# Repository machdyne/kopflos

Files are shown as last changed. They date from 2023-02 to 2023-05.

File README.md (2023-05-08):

# Kopflos Computer

Kopflos is a headless FPGA computer designed by Lone Dynamics Corporation.

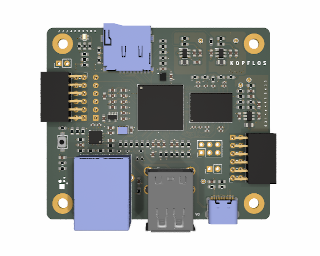
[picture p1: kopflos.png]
Kopflos Computer


This repo contains schematics, PCB layouts, pinouts, a 3D-printable case, example gateware and documentation.

Find more information on the [Kopflos product page](https://machdyne.com/product/kopflos-computer/).

## Programming Kopflos

Kopflos has a JTAG interface and ships with a [DFU bootloader](https://github.com/machdyne/tinydfu-bootloader) that allows the included flash [MMOD](https://machdyne.com/product/mmod) to be programmed over the USB-C port.

### DFU

The DFU bootloader is available for 5 seconds after power-on, issuing a DFU command during this period will stop the boot process until the DFU device is detached. If no command is received the boot process will continue and the user gateware will be loaded.

Install [dfu-util](http://dfu-util.sourceforge.net) (Debian/Ubuntu):

```
$ sudo apt install dfu-util
```

Update the user gateware on the flash MMOD:

```
$ sudo dfu-util -a 0 -D image.bit
```

Detach the DFU device and continue the boot process:

```
$ sudo dfu-util -a 0 -e
```

It is possible to update the bootloader itself using DFU but you shouldn't attempt this unless you have a JTAG programmer (or another method to program the MMOD) available, in case you need to restore the bootloader.

### JTAG

These examples assume you're using a "USB Blaster" JTAG cable, see the header pinout below. You will need to have [openFPGALoader](https://github.com/trabucayre/openFPGALoader) installed.

Program the configuration SRAM:

```
openFPGALoader -c usb-blaster image.bit
```

Program the flash MMOD:

```
openFPGALoader -f -c usb-blaster images/bootloader/tinydfu_kopflos.bit
```

## Blinky 

Building the blinky example requires [Yosys](https://github.com/YosysHQ/yosys), [nextpnr-ecp5](https://github.com/YosysHQ/nextpnr) and [Project Trellis](https://github.com/YosysHQ/prjtrellis).

Assuming they are installed, you can simply type `make` to build the gateware, which will be written to output/blinky.bin. You can then use [openFPGALoader](https://github.com/trabucayre/openFPGALoader) or dfu-util to write the gateware to the device.

## Linux

See the [Kakao Linux](https://github.com/machdyne/kakao) repo for detailed installation instructions.

## JTAG Header

The 3.3V JTAG header can be used to program the FPGA SRAM as well as the MMOD flash memory.

```
2 4 6
1 3 5
```

| Pin | Signal |
| --- | --- |
| 1 | TCK |
| 2 | TDI |
| 3 | TDO |
| 4 | TMS |
| 5 | 3V3 (out) |
| 6 | GND |

## Board Revisions

| Revision | Notes |
| --- | ----- |
| V0 | Initial version |

## License

The contents of this repo are released under the [Lone Dynamics Open License](LICENSE.md) with the following exceptions:

- The KiCad design files contain parts of the [kicad-pmod](https://github.com/mithro/kicad-pmod) library which is released under the [Apache License, Version 2.0](https://www.apache.org/licenses/LICENSE-2.0.html).

- The KiCad design files may contain symbols and footprints released under other licenses; please contact us if we've failed to give proper attribution.

Note: You can use these designs for commercial purposes but we ask that instead of producing exact clones, that you either replace our trademarks and logos with your own or add your own next to ours.

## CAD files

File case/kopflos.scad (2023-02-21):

/*
 * Kopflos Case
 * Copyright (c) 2022 Lone Dynamics Corporation. All rights reserved.
 *
 * required hardware:
 *  - 4 x M3 x 25mm countersunk bolts
 *  - 4 x M3 nuts
 *
 */

$fn = 100;

board_width = 60;
board_thickness = 1.5;
board_length = 70;
board_height = 1.6;
board_spacing = 2;

wall = 1.5;

top_height = 17;
bottom_height = 8;

//mds_board();

translate([0,0,15])
	mds_case_top();

//translate([0,0,-15])
//	mds_case_bottom();

module mds_board() {
	
	translate([wall, wall, 0]) {
		difference() {
			color([0,0.5,0])
				roundedcube(board_width,board_length,board_thickness,3);
			translate([5, 5, -1]) cylinder(d=3.2, h=10);
			translate([5, 65, -1]) cylinder(d=3.2, h=10);
			translate([55, 5, -1]) cylinder(d=3.2, h=10);
			translate([55, 65, -1]) cylinder(d=3.2, h=10);
		}	
	}
	
}

module mds_case_top() {
	
	difference() {
				
		color([0.5,0.5,0.5])
			roundedcube(board_width+(wall*2),board_length+(wall*2),top_height,2.5);

		// cutouts
		translate([2,9,-12])
			roundedcube(board_width-3,board_length-15,13.75,2.5);

		translate([2,9,-2])
			roundedcube(board_width-6,board_length-15,13.75,2.5);

		translate([9,3,-2])
			roundedcube(board_width-15,board_length-3,17.75,2.5);
		
		translate([wall, wall, 0]) {

			// vents
			translate([60/2-(30/2),60,0]) cube([30,1,20]);
			translate([60/2-(30/2),55,0]) cube([30,1,20]);
			translate([60/2-(30/2),50,0]) cube([30,1,20]);
					
			// Ethernet
			translate([40,18.5-(16/2),-1]) cube([30,16,14+1]);

			// USBA
			translate([40,38.5-(16/2),-1]) cube([30,16,15.7+1]);

			// USBC
			translate([40,55-(9.5/2),-1]) cube([30,9.5,3.5+1]);
		
			// SD
			translate([-5,25.3-(15/2),-1]) cube([30,15,2+1]);

			// PMODA
			translate([21.775-(15.6/2),-5,-1]) cube([15.6,30,5+1]);

			// PMODB
			translate([40.675-(15.6/2),65,-1]) cube([15.6,30,5+1]);

			// LED
			translate([-5,11.5-(1.5/2),3.5]) cube([25,1.5,1.5]);
				
			// bolt holes
			translate([5, 5, -21]) cylinder(d=3.5, h=40);
			translate([5, 65, -21]) cylinder(d=3.5, h=40);
			translate([55, 5, -20]) cylinder(d=3.5, h=40);
			translate([55, 65, -21]) cylinder(d=3.5, h=40);

			// flush mount bolt holes
			translate([5, 5, top_height-2]) cylinder(d=5, h=4);
			translate([5, 65, top_height-2]) cylinder(d=5, h=4);
			translate([55, 5, top_height-2]) cylinder(d=5, h=4);
			translate([55, 65, top_height-2]) cylinder(d=5, h=4);

			// eis text
			rotate(270)
				translate([-23.5,30-3,top_height-0.5])
					linear_extrude(1)
						text("K O P F L O S", size=5, halign="center",
							font="Ubuntu:style=Bold");

		}
		
	}	
}

module mds_case_bottom() {
	
	difference() {
		color([0.5,0.5,0.5])
			roundedcube(board_width+(wall*2),board_length+(wall*2),bottom_height,2.5);
		
		// cutouts
		translate([3,10,1.5])
			roundedcube(board_width-3,board_length-17,10,2.5);
				
		translate([10.5,2.5,1.5])
			roundedcube(board_width-17.5,board_length-2,10,2.5);

		translate([wall, wall, 0]) {
			
		// board cutout
		translate([0,0,bottom_height-board_height])
			roundedcube(board_width+0.2,board_length+0.2,board_height+1,2.5);

		translate([wall, wall, 0]) {

			// USB-C
			translate([39,55-(9.5/2),5]) cube([19.75,9.5,10.5+1]);
			
		}

		// bolt holes
		translate([5, 5, -11]) cylinder(d=3.2, h=25);
		translate([5, 65, -11]) cylinder(d=3.2, h=25);
		translate([55, 5, -11]) cylinder(d=3.2, h=25);
		translate([55, 65, -11]) cylinder(d=3.2, h=25);

		// nut holes
		translate([5, 5, -1]) cylinder(d=7, h=2.5+2, $fn=6);
		translate([5, 65, -1]) cylinder(d=7, h=2.5+2, $fn=6);
		translate([55, 5, -1]) cylinder(d=7, h=2.5+2, $fn=6);
		translate([55, 65, -1]) cylinder(d=7, h=2.5+2, $fn=6);

		}
		
	}	
}

// https://gist.github.com/tinkerology/ae257c5340a33ee2f149ff3ae97d9826
module roundedcube(xx, yy, height, radius)
{
    translate([0,0,height/2])
    hull()
    {
        translate([radius,radius,0])
        cylinder(height,radius,radius,true);

        translate([xx-radius,radius,0])
        cylinder(height,radius,radius,true);

        translate([xx-radius,yy-radius,0])
        cylinder(height,radius,radius,true);

        translate([radius,yy-radius,0])
        cylinder(height,radius,radius,true);
    }
}

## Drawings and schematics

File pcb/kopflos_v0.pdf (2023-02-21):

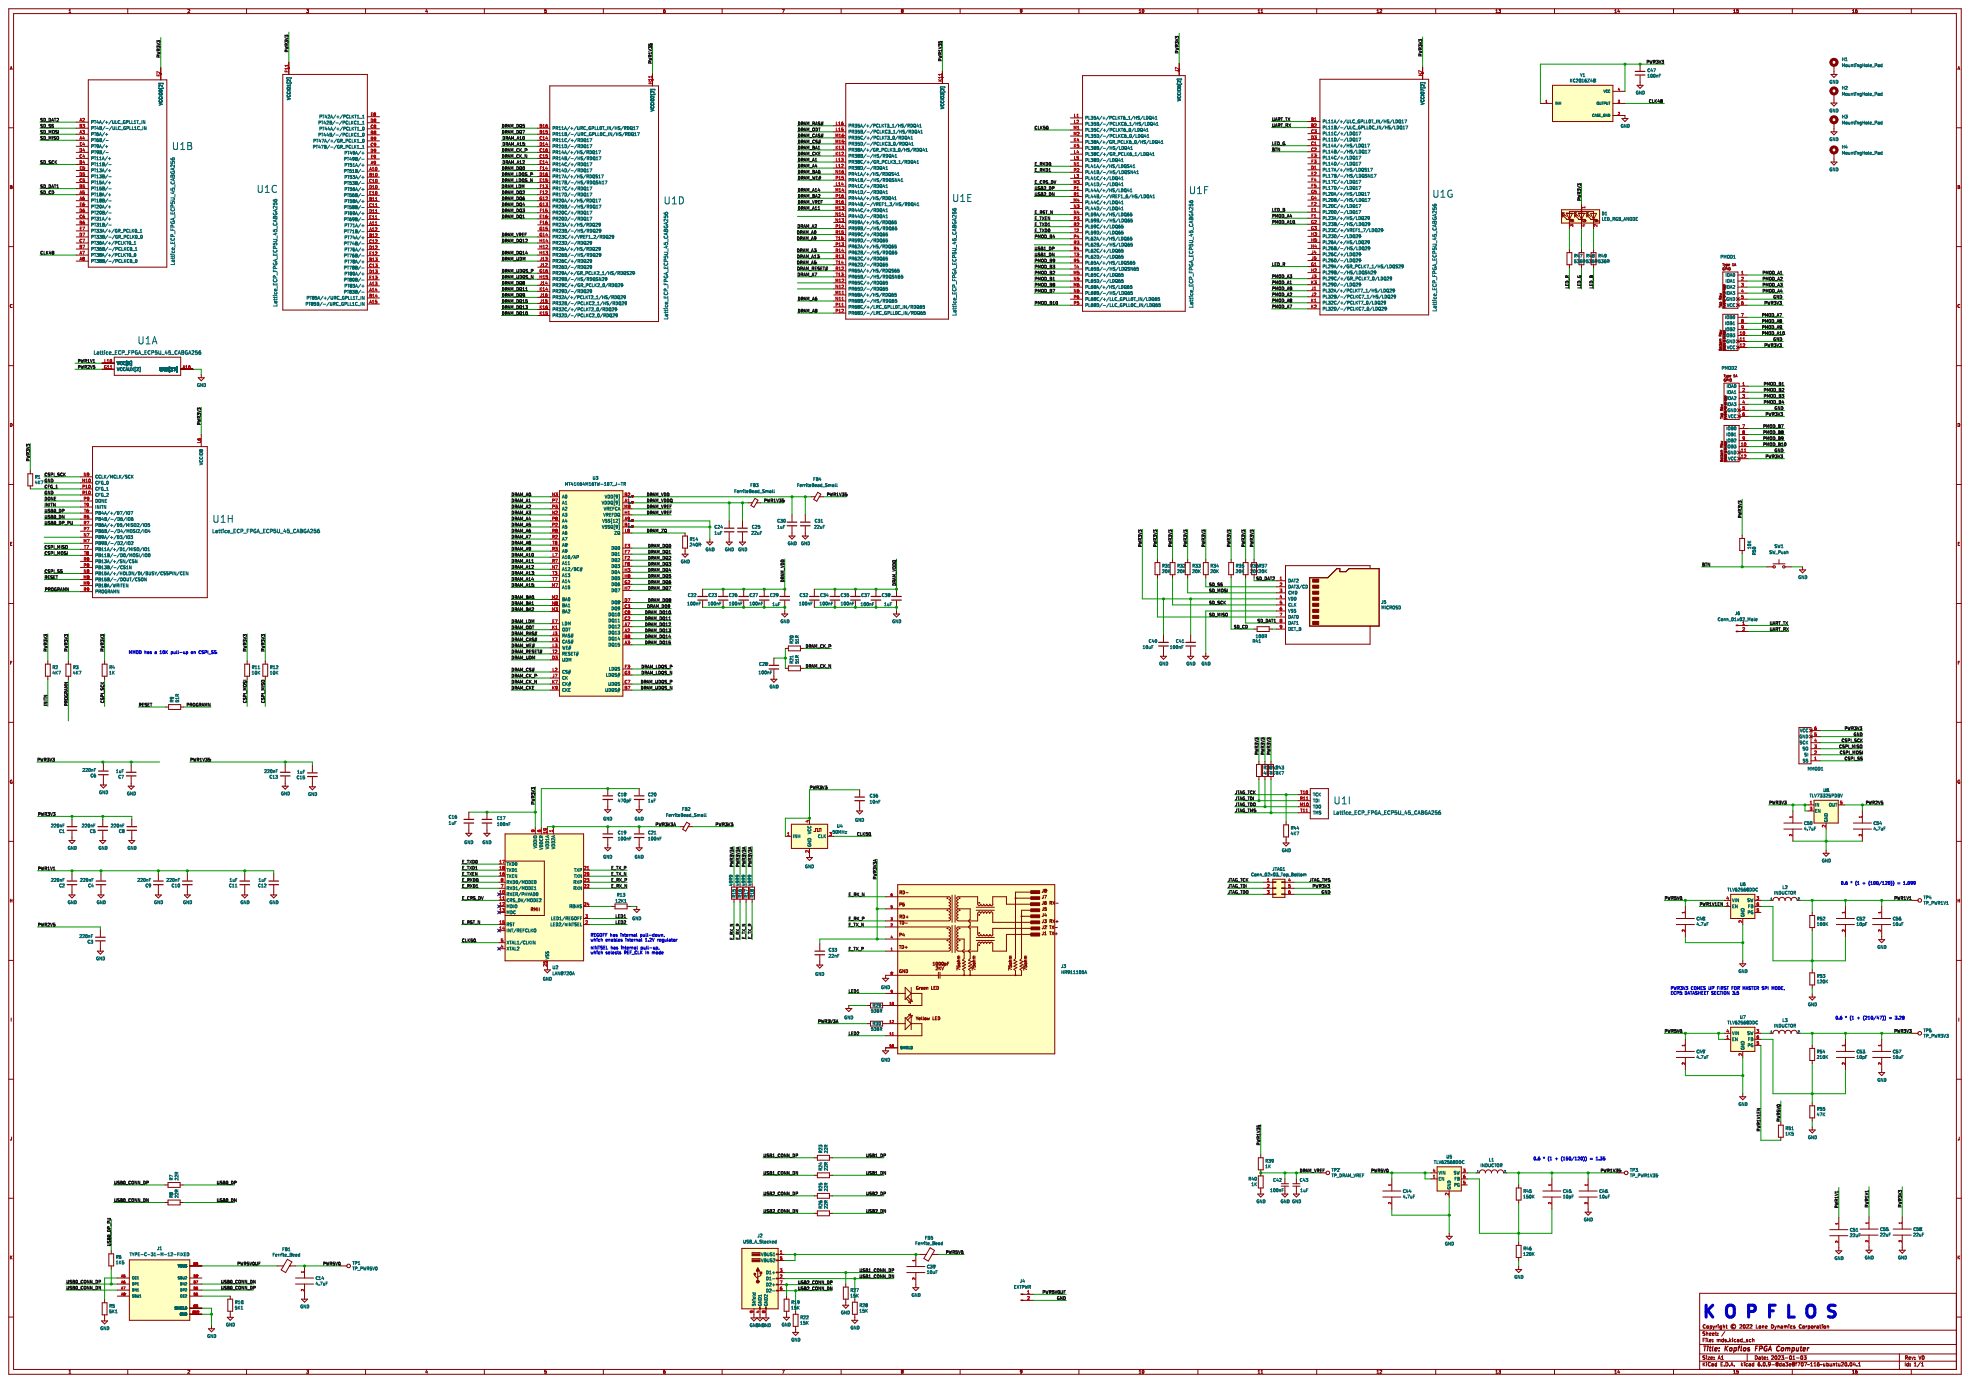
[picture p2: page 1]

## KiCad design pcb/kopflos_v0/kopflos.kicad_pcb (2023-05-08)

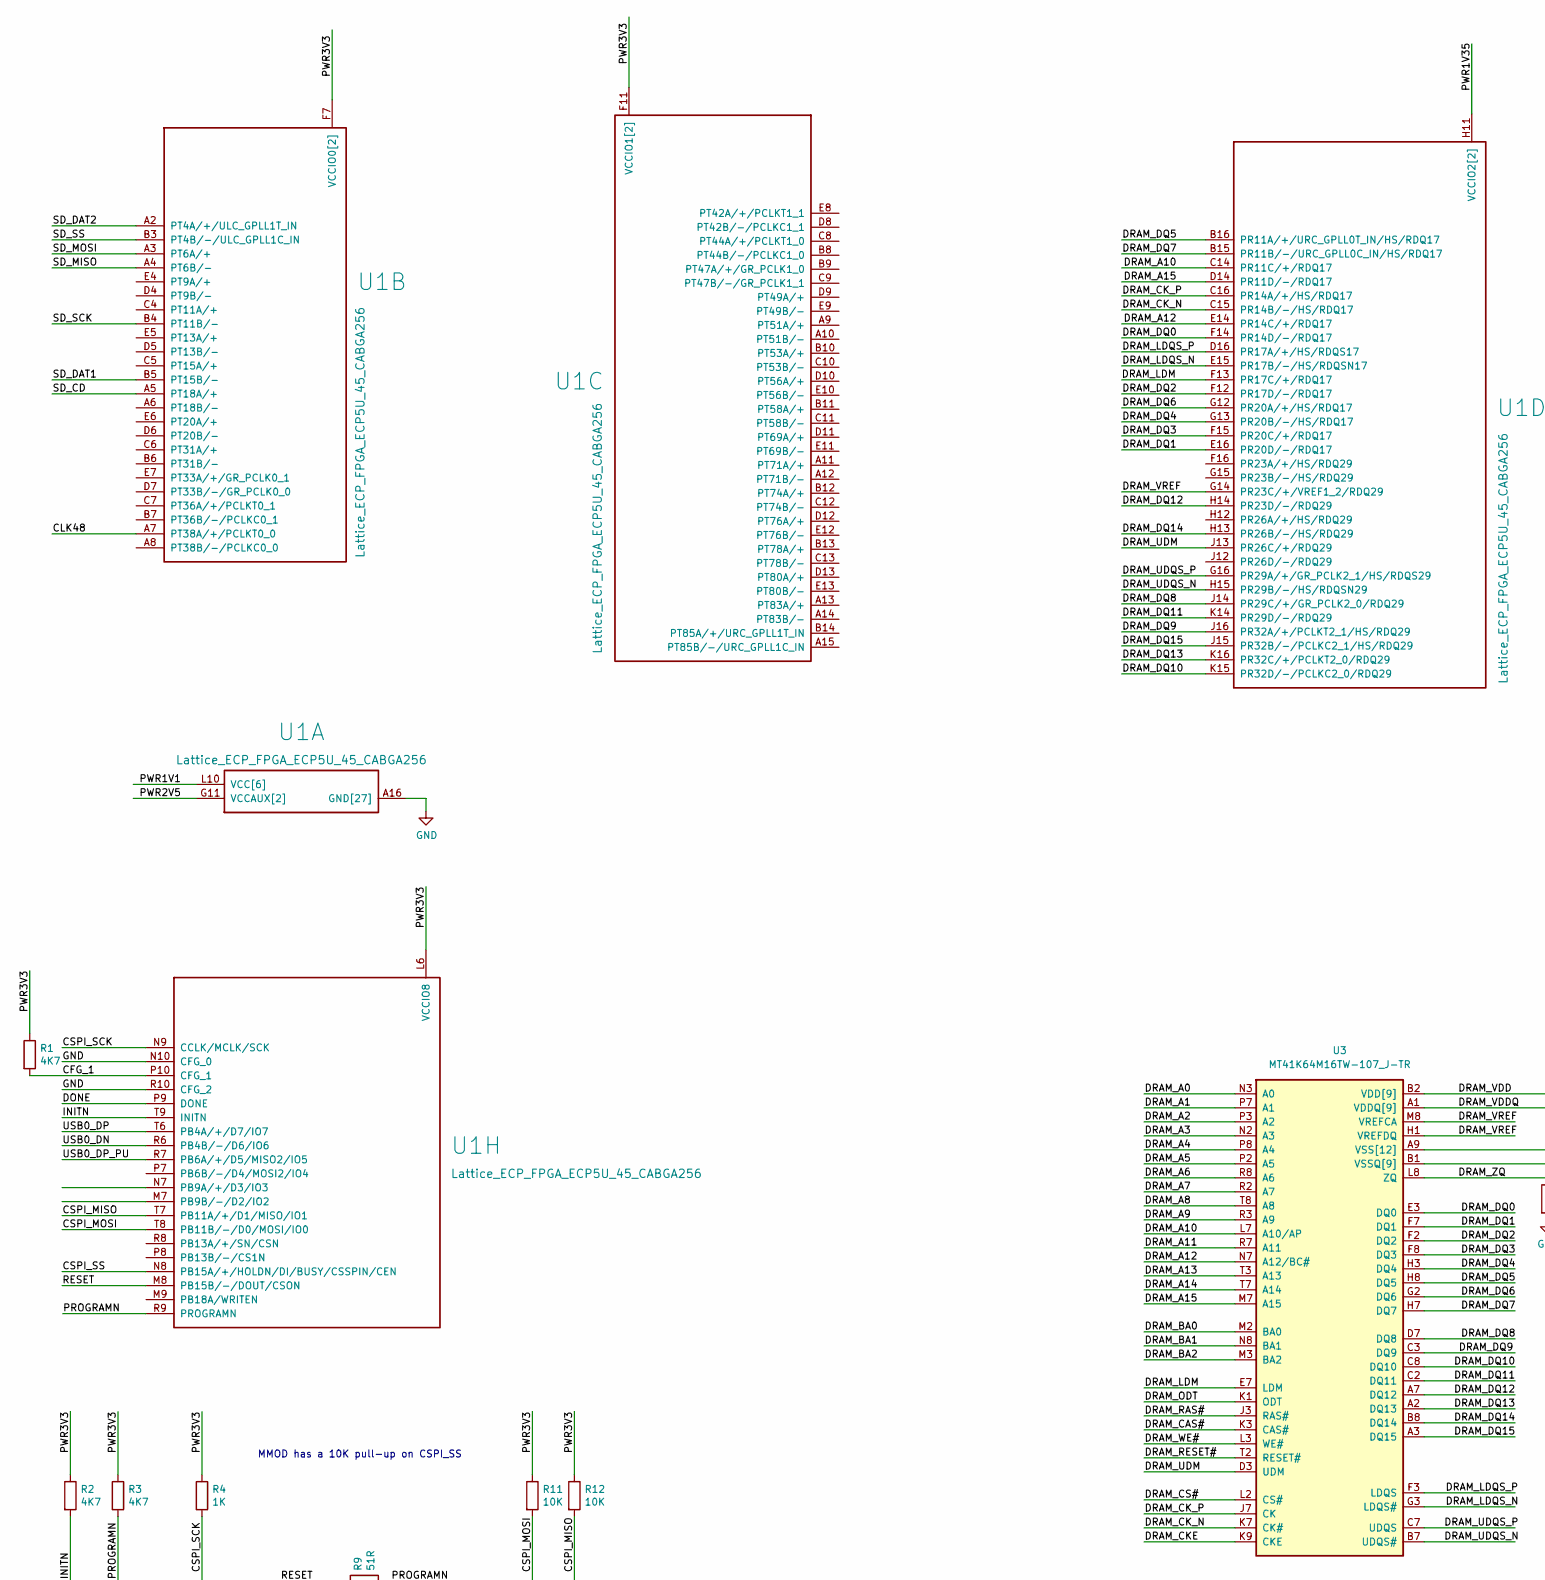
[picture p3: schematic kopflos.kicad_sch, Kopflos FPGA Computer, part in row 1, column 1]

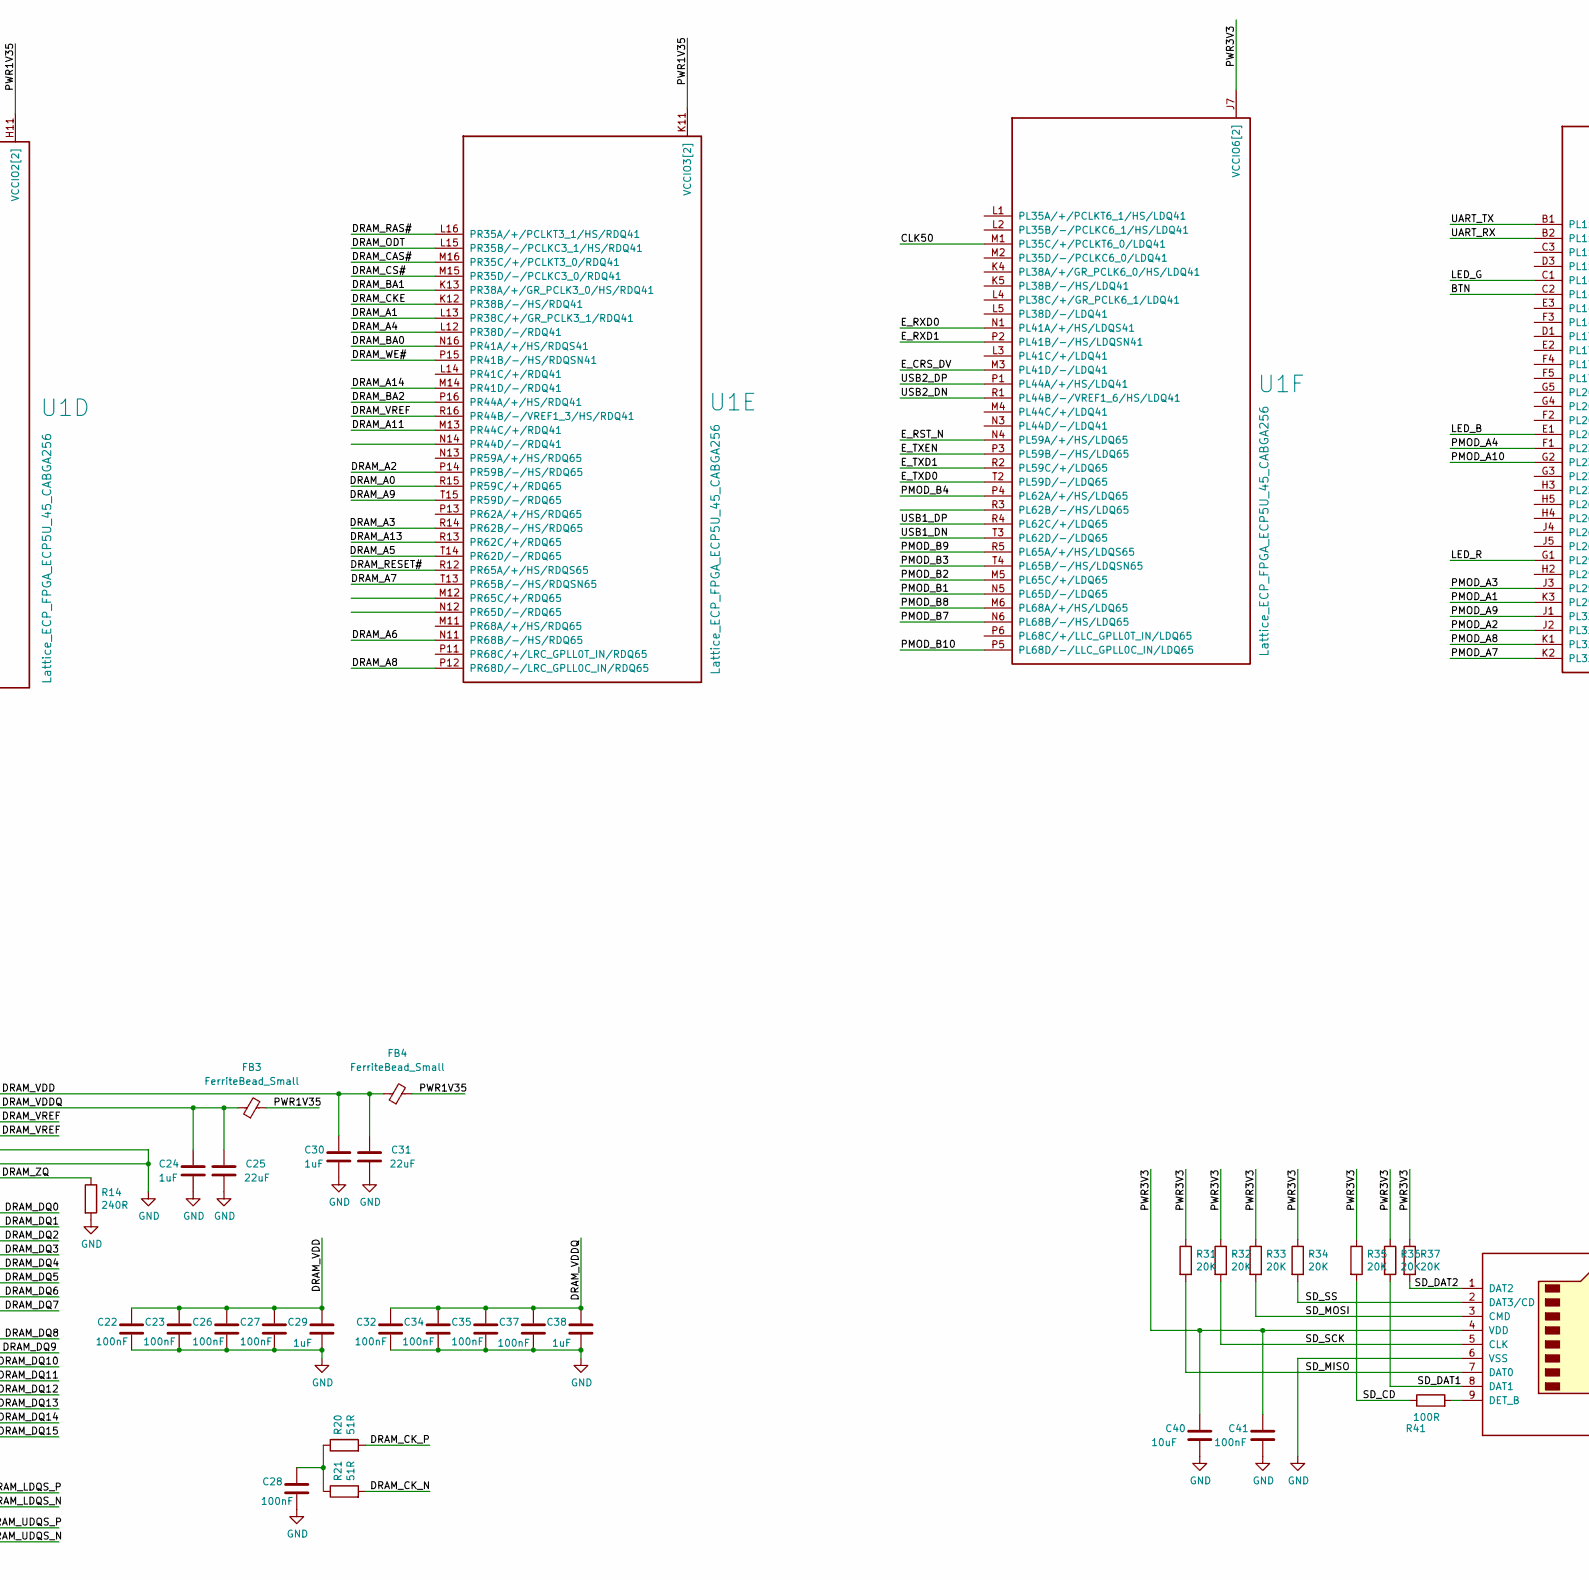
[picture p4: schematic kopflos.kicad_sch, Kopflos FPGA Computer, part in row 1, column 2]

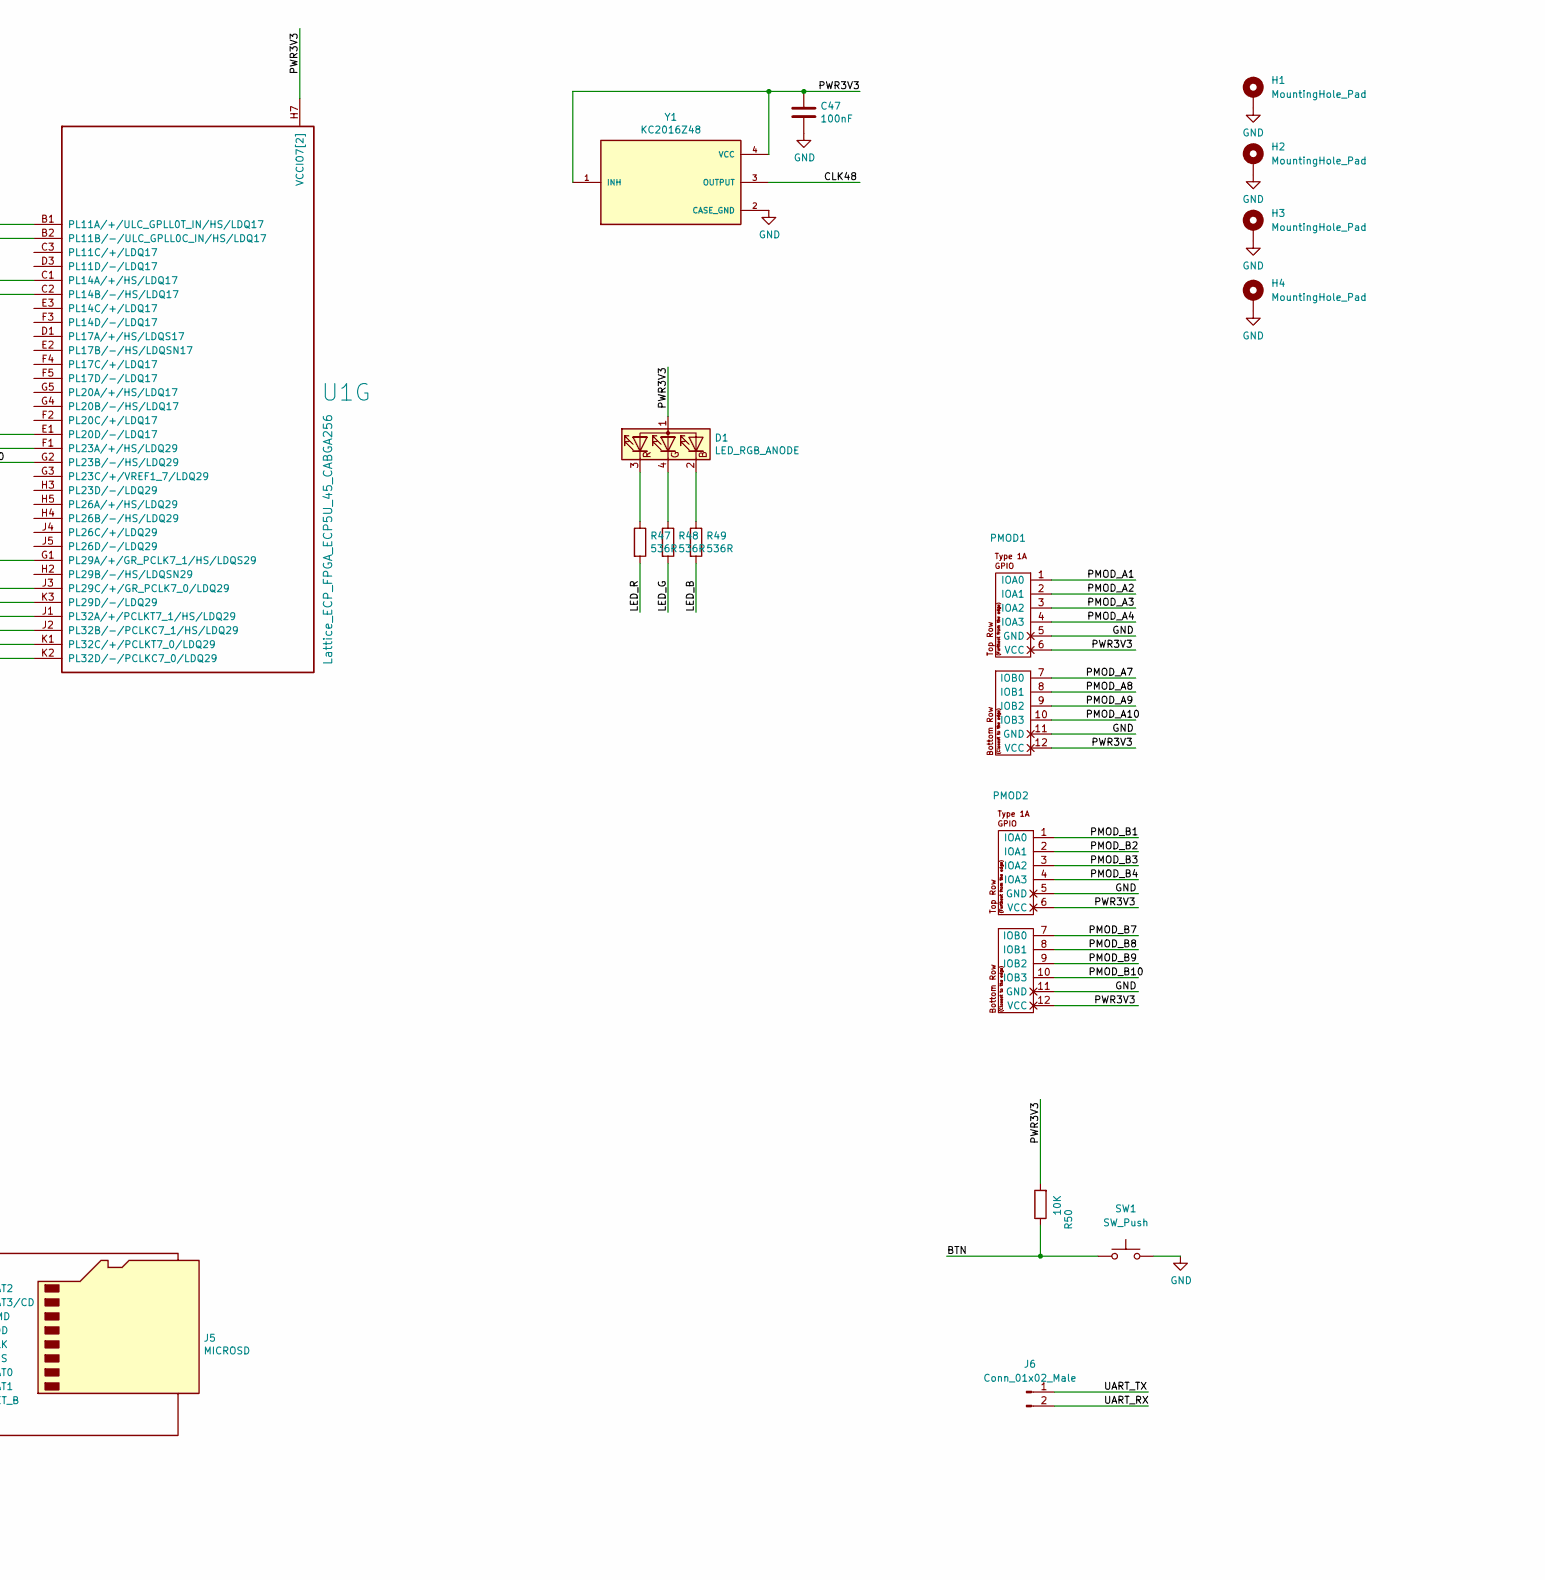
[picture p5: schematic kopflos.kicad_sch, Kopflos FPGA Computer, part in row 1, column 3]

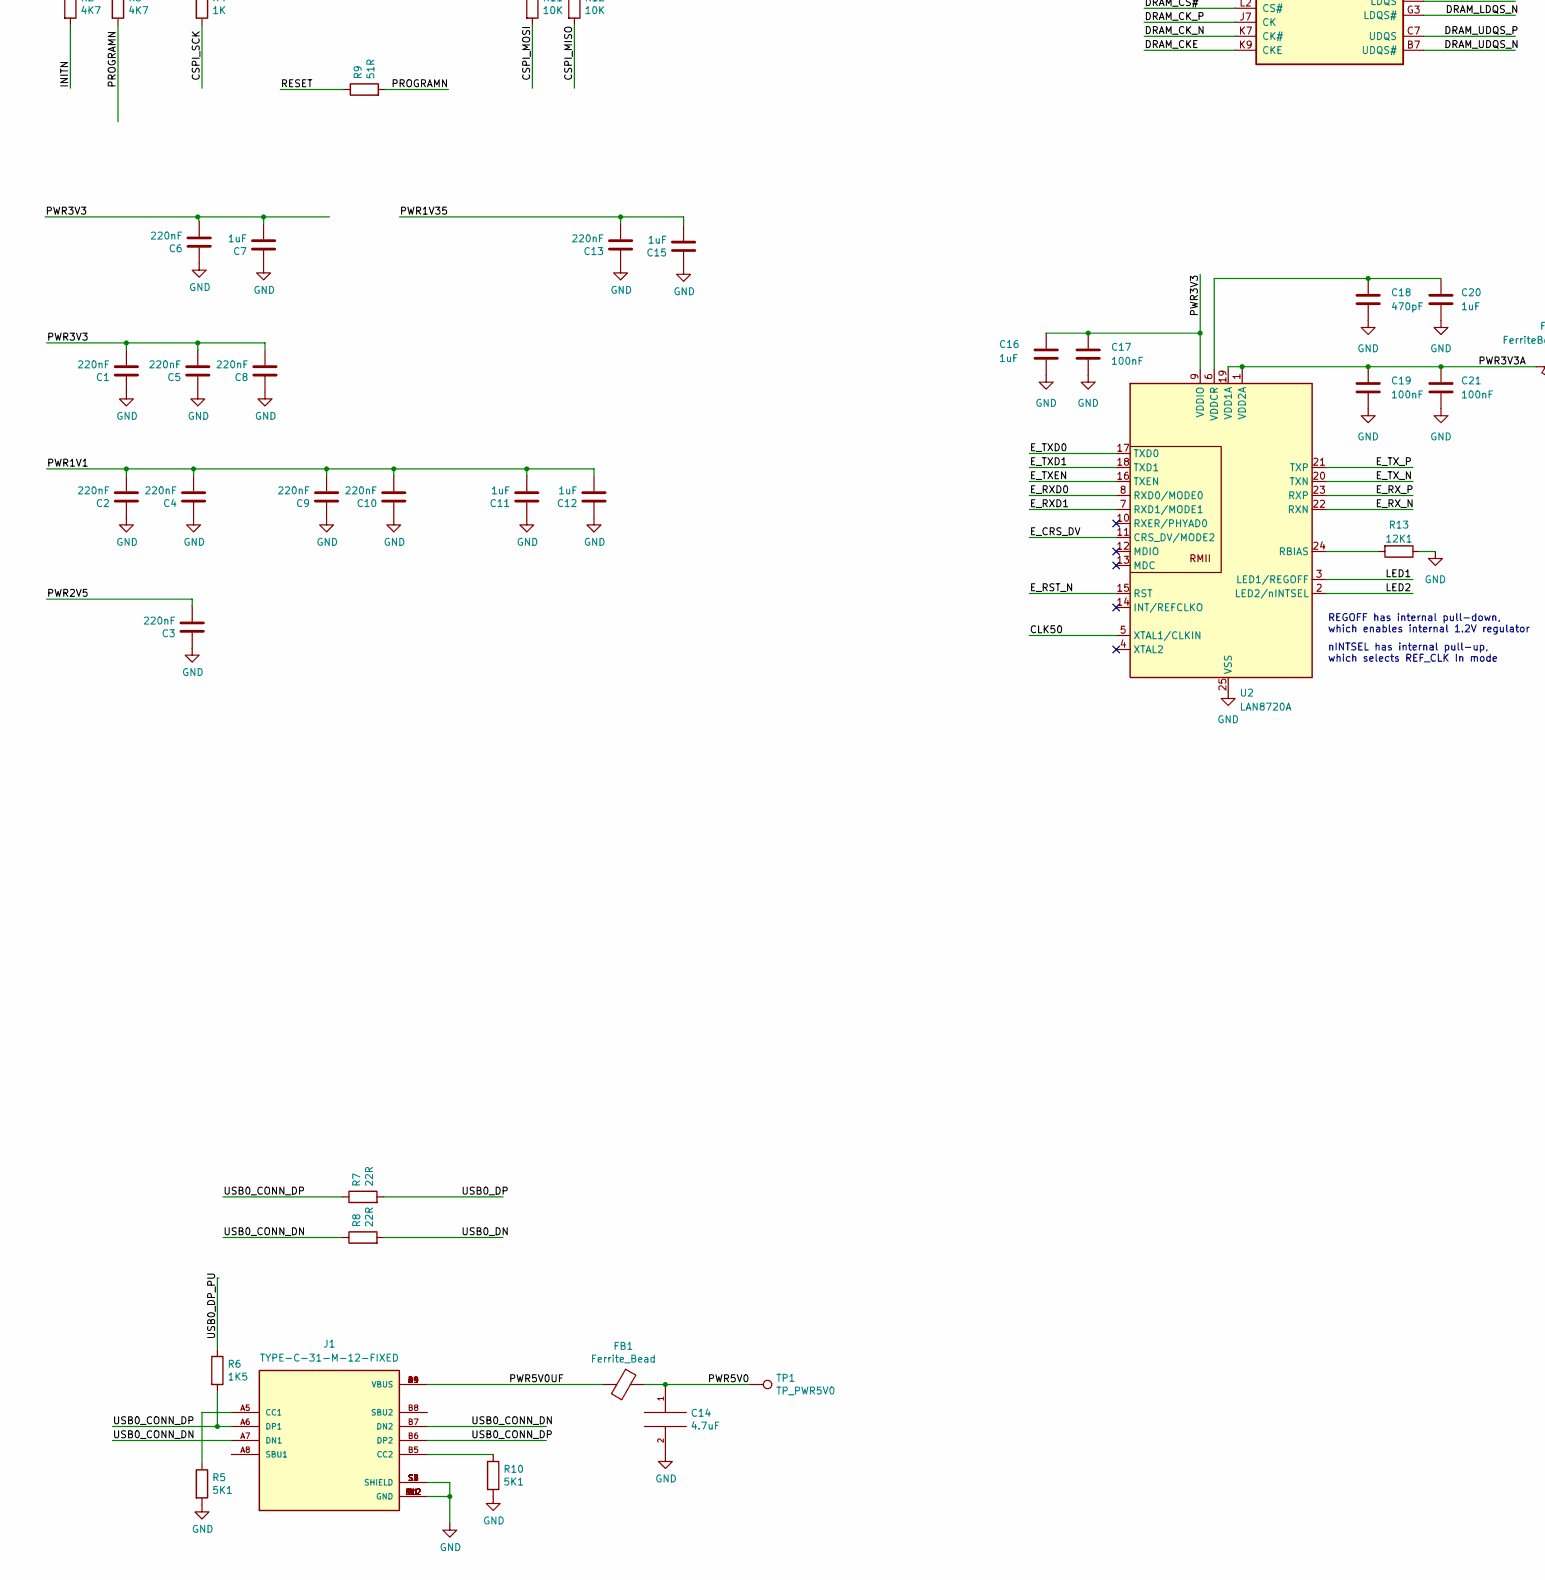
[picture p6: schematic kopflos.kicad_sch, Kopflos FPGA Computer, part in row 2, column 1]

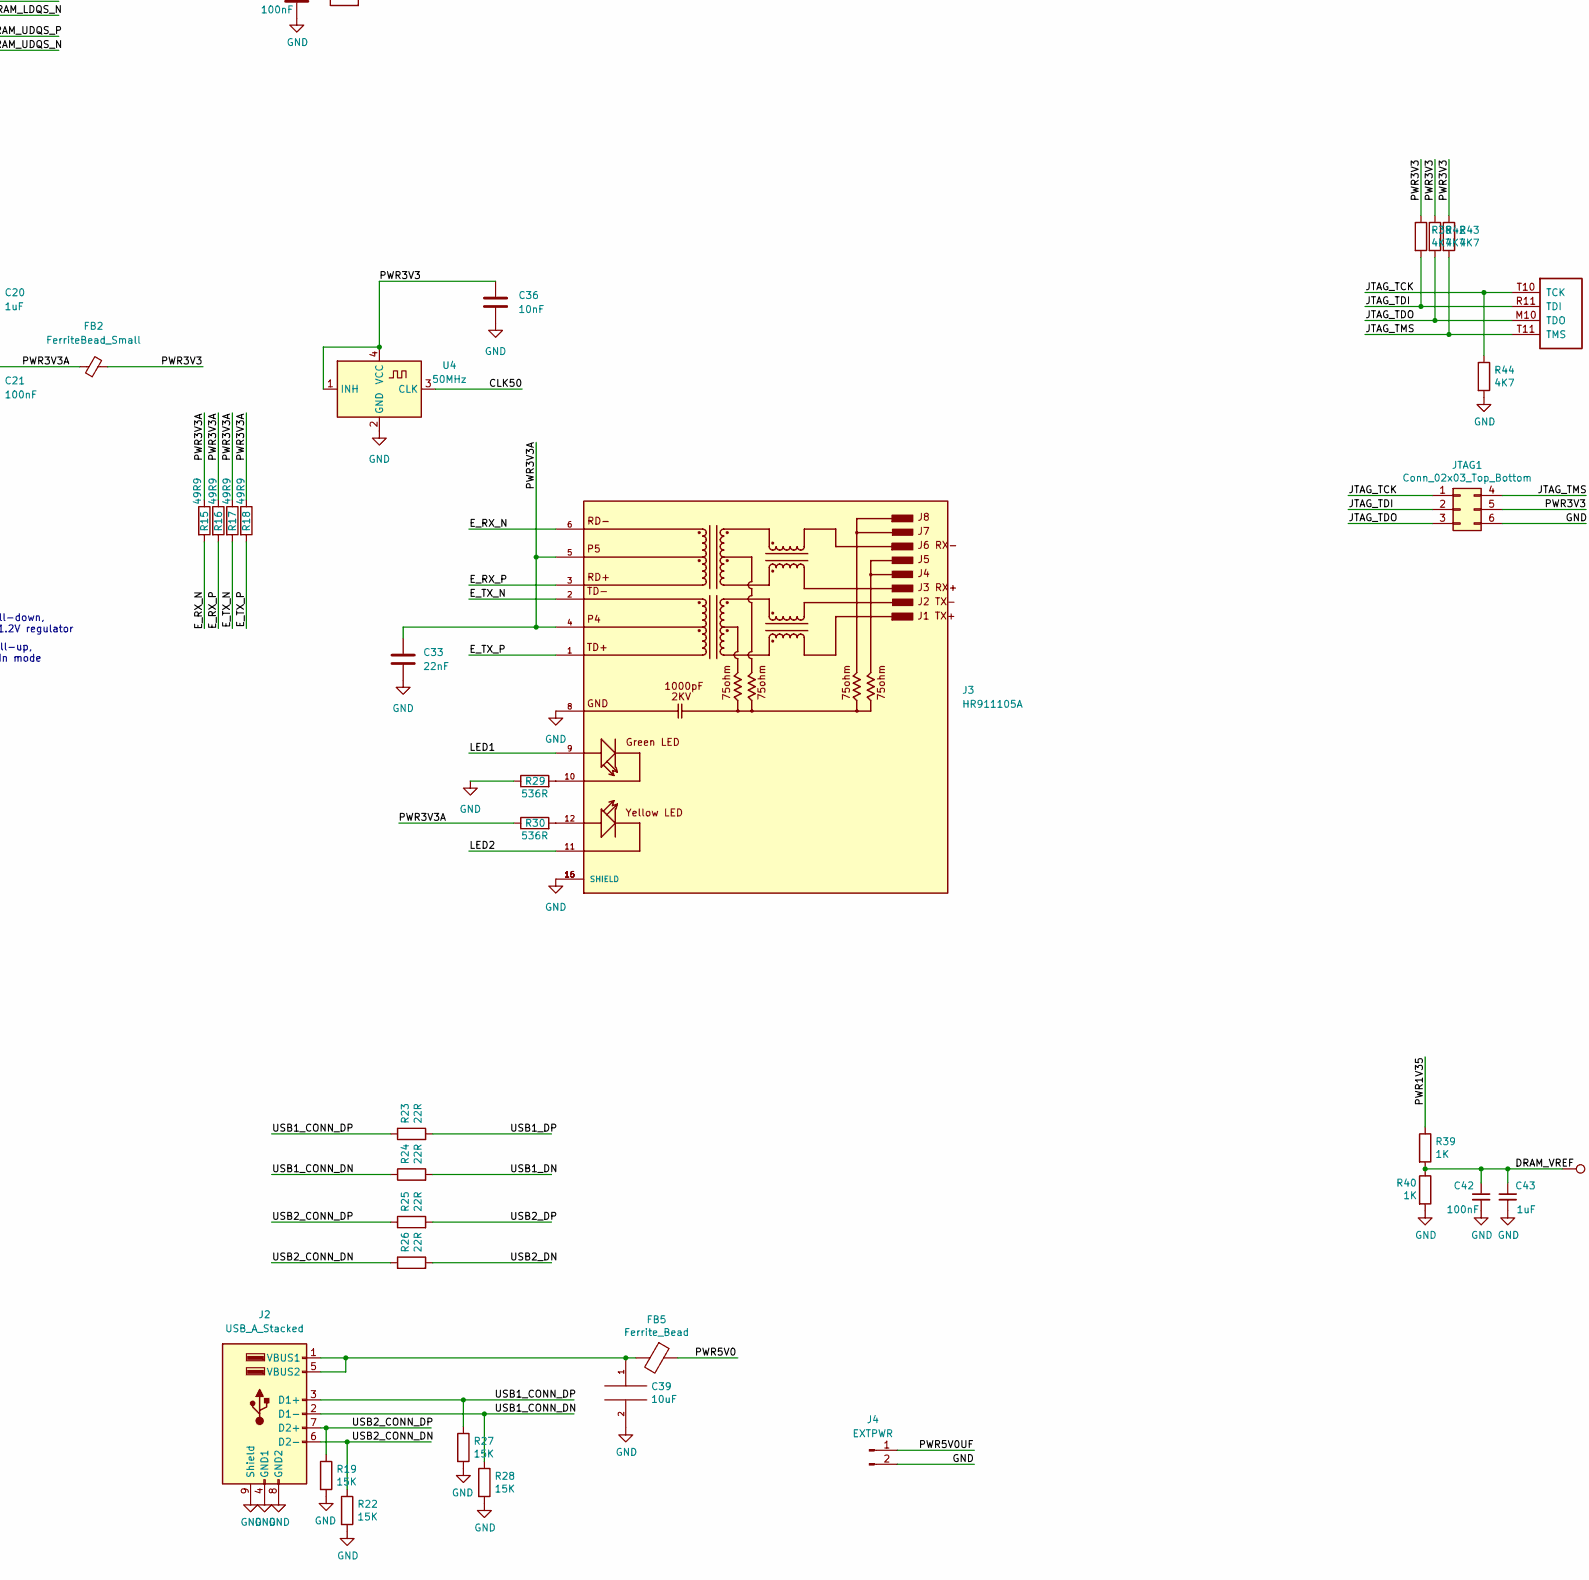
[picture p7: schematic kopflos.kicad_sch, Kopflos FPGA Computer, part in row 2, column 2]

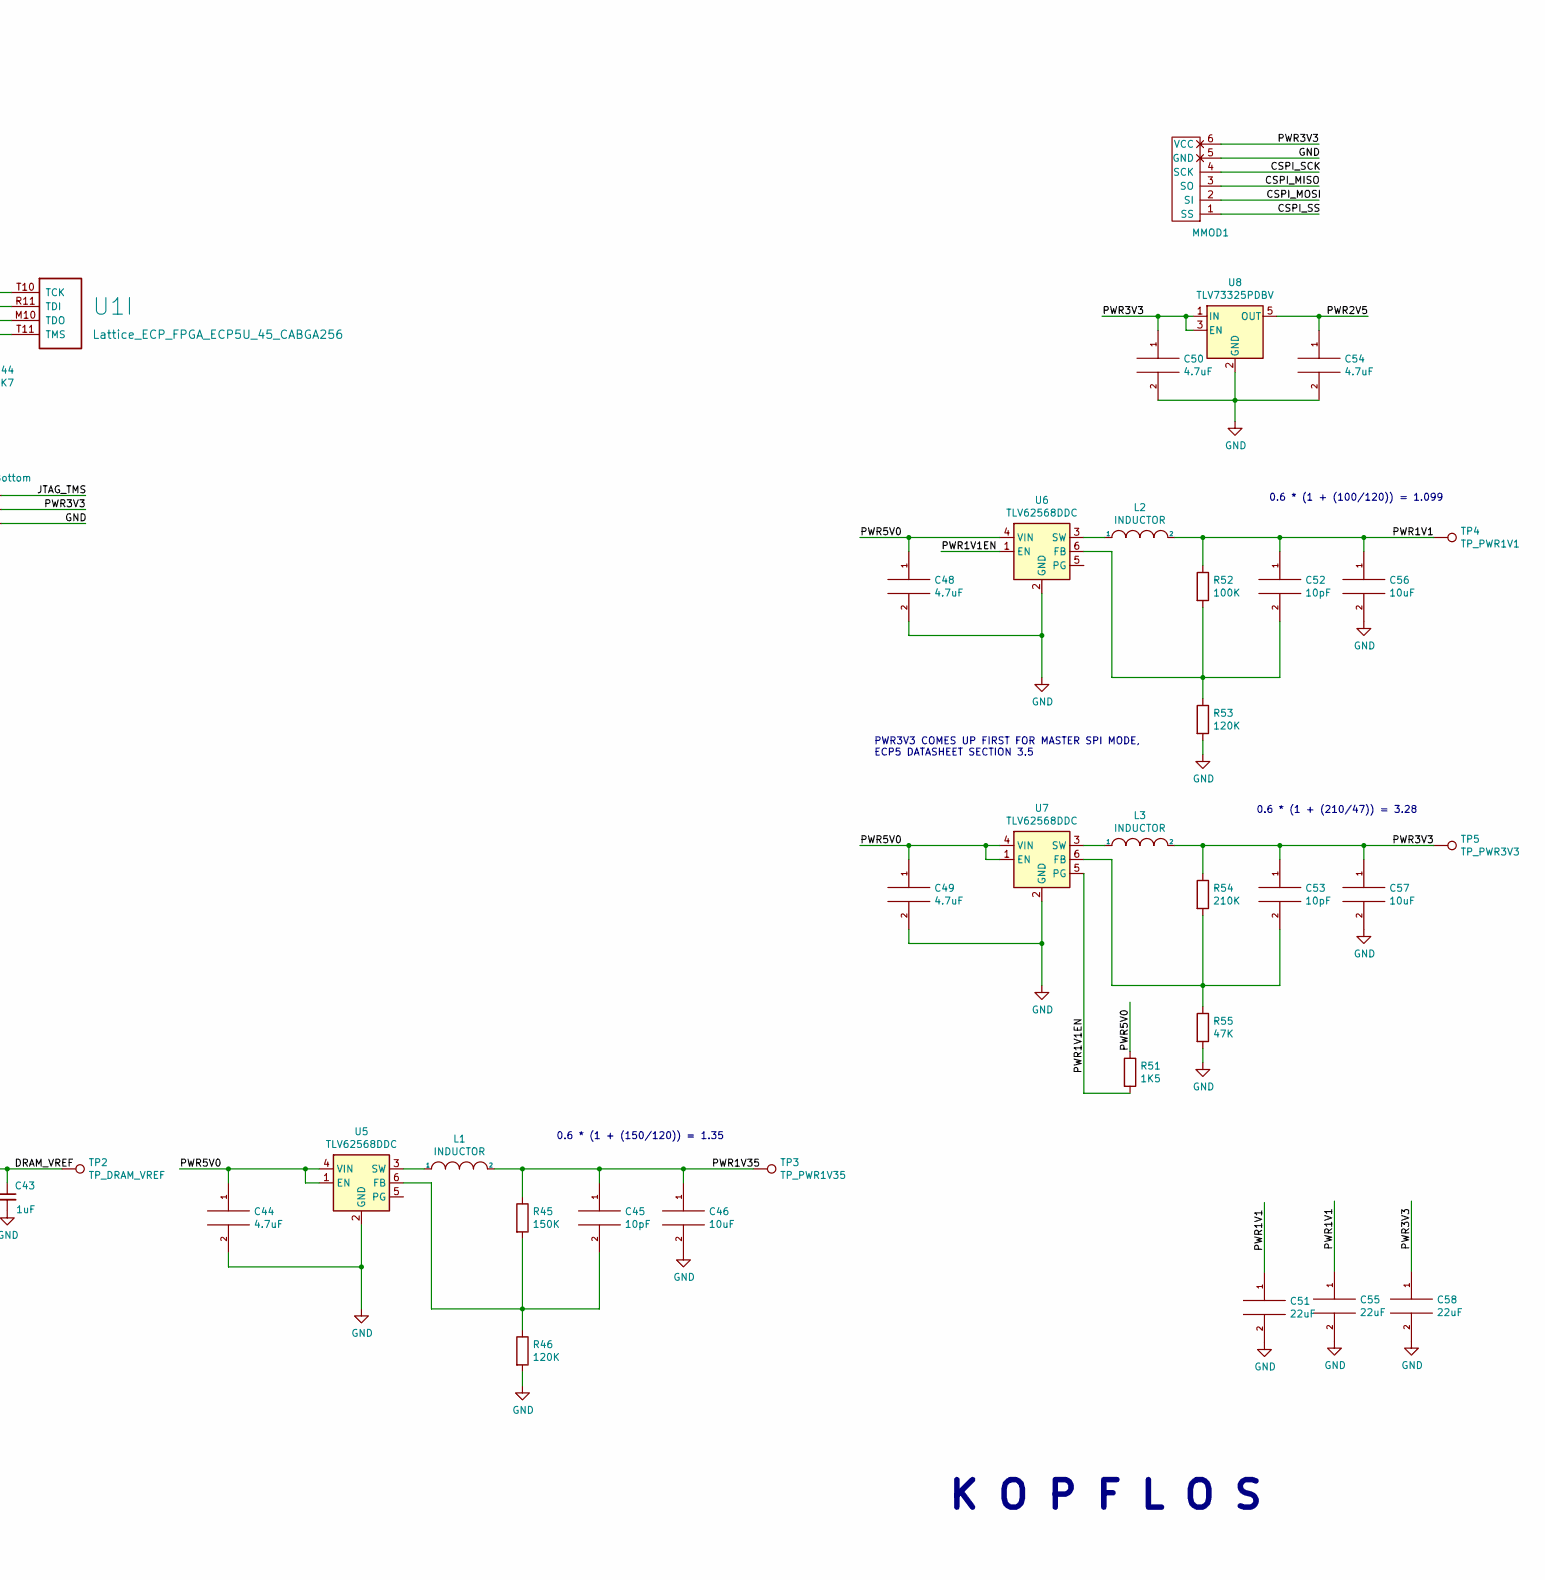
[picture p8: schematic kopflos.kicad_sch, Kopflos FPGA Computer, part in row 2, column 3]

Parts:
C1, C2, C3, C4, C5, C6, C8, C9, C10, C13: 220nF; C_0603_1608Metric
C7, C11, C12, C15, C20, C43: 1uF; C_0603_1608Metric
C14, C44, C48, C49, C50, C54: 4.7uF; C_0603_1608Metric
C16, C24, C29, C30, C38: 1uF; C_0402_1005Metric
C17, C22, C23, C26, C27, C32, C34, C35, C37: 100nF; C_0402_1005Metric
C18: 470pF; C_0603_1608Metric
C19, C21, C42, C47: 100nF; C_0603_1608Metric
C25, C31: 22uF; R_0603_1608Metric
C28, C41: 100nF; R_0603_1608Metric
C33: 22nF; C_0603_1608Metric
C36: 10nF; C_0603_1608Metric
C39, C46, C56, C57: 10uF; C_0603_1608Metric
C40: 10uF; R_0603_1608Metric
C45, C52, C53: 10pF; C_0603_1608Metric
C51, C55, C58: 22uF; C_0603_1608Metric
D1: LED_RGB_ANODE; LED_RGB_0606_CHANZON
FB1, FB5: Ferrite_Bead; R_0603_1608Metric
FB2, FB3, FB4: FerriteBead_Small; R_0603_1608Metric
H1, H2, H3, H4: MountingHole_Pad; MountingHole_3.2mm_M3_Pad
J1: TYPE-C-31-M-12-FIXED; USB_C_Receptacle_HRO_TYPE-C-31-M-12-BIG-PADS; PARTREV A
J2: USB_A_Stacked; USB_A_Wuerth_61400826021_Horizontal_Stacked
J3: HR911105A; HANRUN_HR911105A; PARTREV A
J4: EXTPWR; PinHeader_1x02_P2.54mm_Vertical
J5: MICROSD; SDCARD
J6: Conn_01x02_Male; PinHeader_1x02_P2.54mm_Vertical
JTAG1: Conn_02x03_Top_Bottom; PinHeader_2x03_P2.54mm_Vertical
L1, L2, L3: INDUCTOR; L_0805_2012Metric
MMOD1: PMOD-Device-x1-Type-2-SPI; MMOD_Host_Socket
PMOD1, PMOD2: PMOD-Device-x2-Type-1A-GPIO; PMOD_2x06_HOST
R1, R2, R3, R38, R42, R43, R44: 4K7; R_0603_1608Metric
R4, R39, R40: 1K; R_0603_1608Metric
R5, R10: 5K1; R_0603_1608Metric
R6: 1K5; R_0402_1005Metric
R7, R8, R23, R24, R25, R26: 22R; R_0603_1608Metric
R9, R20, R21: 51R; R_0603_1608Metric
R11, R12, R50: 10K; R_0603_1608Metric
R13: 12K1; R_0603_1608Metric
R14: 240R; R_0603_1608Metric
R15, R16, R17, R18: 49R9; R_0603_1608Metric
R19, R22, R27, R28: 15K; R_0402_1005Metric
R29, R30, R47, R48, R49: 536R; R_0603_1608Metric
R31, R32, R33, R34, R35, R36, R37: 20K; R_0603_1608Metric
R41: 100R; R_0603_1608Metric
R45: 150K; R_0603_1608Metric
R46, R53: 120K; R_0603_1608Metric
R51: 1K5; R_0603_1608Metric
R52: 100K; R_0603_1608Metric
R54: 210K; R_0603_1608Metric
R55: 47K; R_0603_1608Metric
SW1: SW_Push; Button_2P_3x4mm
TP1: TP_PWR5V0; TestPoint_THTPad_D1.0mm_Drill0.5mm
TP2: TP_DRAM_VREF; TestPoint_THTPad_D1.0mm_Drill0.5mm
TP3: TP_PWR1V35; TestPoint_THTPad_D1.0mm_Drill0.5mm
TP4: TP_PWR1V1; TestPoint_THTPad_D1.0mm_Drill0.5mm
TP5: TP_PWR3V3; TestPoint_THTPad_D1.0mm_Drill0.5mm
U1: Lattice_ECP_FPGA_ECP5U_45_CABGA256; BGA-256_14.0x14.0mm_Layout16x16_P0.8mm_Ball0.45mm_Pad0.32mm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
U2: LAN8720A; QFN-24-1EP_4x4mm_P0.5mm_EP2.6x2.6mm
U3: MT41K64M16TW-107_J-TR; BGA-96_9.0x13.0mm_Layout2x3x16_P0.8mm
U4: 50MHz; Oscillator_SMD_Kyocera_KC2520Z-4Pin_2.5x2.0mm
U5, U6, U7: TLV62568DDC; SOT-23-6
U8: TLV73325PDBV; SOT-23-5
Y1: KC2016Z48; OSC_KC2016Z13.5600C1KX00; PARTREV November 2020

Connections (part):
/BTN: R50.1, SW1.1, U1.C2 (PL14B/-/HS/LDQ17)
/CFG_1: R1.2, U1.P10 (CFG_1)
/CLK48: U1.A7 (PT38A/+/PCLKT0_0), Y1.3 (OUTPUT)
/CLK50: U1.M1 (PL35C/+/PCLKT6_0/LDQ41), U2.5 (XTAL1/CLKIN), U4.3 (CLK)
/CSPI_MISO: MMOD1.3 (SO), R12.2, U1.T7 (PB11A/+/D1/MISO/IO1)
/CSPI_MOSI: MMOD1.2 (SI), R11.2, U1.T8 (PB11B/-/D0/MOSI/IO0)
/CSPI_SCK: MMOD1.4 (SCK), R4.2, U1.N9 (CCLK/MCLK/SCK)
/CSPI_SS: MMOD1.1 (SS), U1.N8 (PB15A/+/HOLDN/DI/BUSY/CSSPIN/CEN)
/DONE: U1.P9 (DONE)
/DRAM_A0: U1.R15 (PR59C/+/RDQ65), U3.N3 (A0)
/DRAM_A1: U1.L13 (PR38C/+/GR_PCLK3_1/RDQ41), U3.P7 (A1)
/DRAM_A2: U1.P14 (PR59B/-/HS/RDQ65), U3.P3 (A2)
/DRAM_A3: U1.R14 (PR62B/-/HS/RDQ65), U3.N2 (A3)
/DRAM_A4: U1.L12 (PR38D/-/RDQ41), U3.P8 (A4)
/DRAM_A5: U1.T14 (PR62D/-/RDQ65), U3.P2 (A5)
/DRAM_A6: U1.N11 (PR68B/-/HS/RDQ65), U3.R8 (A6)
/DRAM_A7: U1.T13 (PR65B/-/HS/RDQSN65), U3.R2 (A7)
/DRAM_A8: U1.P12 (PR68D/-/LRC_GPLL0C_IN/RDQ65), U3.T8 (A8)
/DRAM_A9: U1.T15 (PR59D/-/RDQ65), U3.R3 (A9)
/DRAM_A10: U1.C14 (PR11C/+/RDQ17), U3.L7 (A10/AP)
/DRAM_A11: U1.M13 (PR44C/+/RDQ41), U3.R7 (A11)
/DRAM_A12: U1.E14 (PR14C/+/RDQ17), U3.N7 (A12/BC#)
/DRAM_A13: U1.R13 (PR62C/+/RDQ65), U3.T3 (A13)
/DRAM_A14: U1.M14 (PR41D/-/RDQ41), U3.T7 (A14)
/DRAM_A15: U1.D14 (PR11D/-/RDQ17), U3.M7 (A15)
/DRAM_BA0: U1.N16 (PR41A/+/HS/RDQS41), U3.M2 (BA0)
/DRAM_BA1: U1.K13 (PR38A/+/GR_PCLK3_0/HS/RDQ41), U3.N8 (BA1)
/DRAM_BA2: U1.P16 (PR44A/+/HS/RDQ41), U3.M3 (BA2)
/DRAM_CAS#: U1.M16 (PR35C/+/PCLKT3_0/RDQ41), U3.K3 (CAS#)
/DRAM_CKE: U1.K12 (PR38B/-/HS/RDQ41), U3.K9 (CKE)
/DRAM_CK_N: R21.2, U1.C15 (PR14B/-/HS/RDQ17), U3.K7 (CK#)
/DRAM_CK_P: R20.2, U1.C16 (PR14A/+/HS/RDQ17), U3.J7 (CK)
/DRAM_CS#: U1.M15 (PR35D/-/PCLKC3_0/RDQ41), U3.L2 (CS#)
/DRAM_DQ0: U1.F14 (PR14D/-/RDQ17), U3.E3 (DQ0)
/DRAM_DQ1: U1.E16 (PR20D/-/RDQ17), U3.F7 (DQ1)
/DRAM_DQ2: U1.F12 (PR17D/-/RDQ17), U3.F2 (DQ2)
/DRAM_DQ3: U1.F15 (PR20C/+/RDQ17), U3.F8 (DQ3)
/DRAM_DQ4: U1.G13 (PR20B/-/HS/RDQ17), U3.H3 (DQ4)
/DRAM_DQ5: U1.B16 (PR11A/+/URC_GPLL0T_IN/HS/RDQ17), U3.H8 (DQ5)
/DRAM_DQ6: U1.G12 (PR20A/+/HS/RDQ17), U3.G2 (DQ6)
/DRAM_DQ7: U1.B15 (PR11B/-/URC_GPLL0C_IN/HS/RDQ17), U3.H7 (DQ7)
/DRAM_DQ8: U1.J14 (PR29C/+/GR_PCLK2_0/RDQ29), U3.D7 (DQ8)
/DRAM_DQ9: U1.J16 (PR32A/+/PCLKT2_1/HS/RDQ29), U3.C3 (DQ9)
/DRAM_DQ10: U1.K15 (PR32D/-/PCLKC2_0/RDQ29), U3.C8 (DQ10)
/DRAM_DQ11: U1.K14 (PR29D/-/RDQ29), U3.C2 (DQ11)
/DRAM_DQ12: U1.H14 (PR23D/-/RDQ29), U3.A7 (DQ12)
/DRAM_DQ13: U1.K16 (PR32C/+/PCLKT2_0/RDQ29), U3.A2 (DQ13)
/DRAM_DQ14: U1.H13 (PR26B/-/HS/RDQ29), U3.B8 (DQ14)
/DRAM_DQ15: U1.J15 (PR32B/-/PCLKC2_1/HS/RDQ29), U3.A3 (DQ15)
/DRAM_LDM: U1.F13 (PR17C/+/RDQ17), U3.E7 (LDM)
/DRAM_LDQS_N: U1.E15 (PR17B/-/HS/RDQSN17), U3.G3 (LDQS#)
/DRAM_LDQS_P: U1.D16 (PR17A/+/HS/RDQS17), U3.F3 (LDQS)
/DRAM_ODT: U1.L15 (PR35B/-/PCLKC3_1/HS/RDQ41), U3.K1 (ODT)
/DRAM_RAS#: U1.L16 (PR35A/+/PCLKT3_1/HS/RDQ41), U3.J3 (RAS#)
/DRAM_RESET#: U1.R12 (PR65A/+/HS/RDQS65), U3.T2 (RESET#)
/DRAM_UDM: U1.J13 (PR26C/+/RDQ29), U3.D3 (UDM)
/DRAM_UDQS_N: U1.H15 (PR29B/-/HS/RDQSN29), U3.B7 (UDQS#)
/DRAM_UDQS_P: U1.G16 (PR29A/+/GR_PCLK2_1/HS/RDQS29), U3.C7 (UDQS)
/DRAM_VDD: C22.1, C23.1, C26.1, C27.1, C29.1, C30.1, C31.1, FB4.1, U3.B2 (VDD[9]), U3.D9 (VDD), U3.G7 (VDD), U3.K2 (VDD), U3.K8 (VDD), U3.N1 (VDD), U3.N9 (VDD), U3.R1 (VDD), U3.R9 (VDD)
/DRAM_VDDQ: C24.1, C25.1, C32.1, C34.1, C35.1, C37.1, C38.1, FB3.1, U3.A1 (VDDQ[9]), U3.A8 (VDDQ), U3.C1 (VDDQ), U3.C9 (VDDQ), U3.D2 (VDDQ), U3.E9 (VDDQ), U3.F1 (VDDQ), U3.H2 (VDDQ), U3.H9 (VDDQ)
/DRAM_VREF: C42.1, C43.1, R39.2, R40.1, TP2.1, U1.G14 (PR23C/+/VREF1_2/RDQ29), U1.R16 (PR44B/-/VREF1_3/HS/RDQ41), U3.H1 (VREFDQ), U3.M8 (VREFCA)
/DRAM_WE#: U1.P15 (PR41B/-/HS/RDQSN41), U3.L3 (WE#)
/DRAM_ZQ: R14.1, U3.L8 (ZQ)
/E_CRS_DV: U1.M3 (PL41D/-/LDQ41), U2.11 (CRS_DV/MODE2)
/E_RST_N: U1.N4 (PL59A/+/HS/LDQ65), U2.15 (RST)
/E_RXD0: U1.N1 (PL41A/+/HS/LDQS41), U2.8 (RXD0/MODE0)
/E_RXD1: U1.P2 (PL41B/-/HS/LDQSN41), U2.7 (RXD1/MODE1)
/E_RX_N: J3.6, R15.2, U2.22 (RXN)
/E_RX_P: J3.3, R16.2, U2.23 (RXP)
/E_TXD0: U1.T2 (PL59D/-/LDQ65), U2.17 (TXD0)
/E_TXD1: U1.R2 (PL59C/+/LDQ65), U2.18 (TXD1)
/E_TXEN: U1.P3 (PL59B/-/HS/LDQ65), U2.16 (TXEN)
/E_TX_N: J3.2, R17.2, U2.20 (TXN)
/E_TX_P: J3.1, R18.2, U2.21 (TXP)
/INITN: R2.2, U1.T9 (INITN)
/JTAG_TCK: JTAG1.1, R44.1, U1.T10 (TCK)
/JTAG_TDI: JTAG1.2, R38.2, U1.R11 (TDI)
/JTAG_TDO: JTAG1.3, R42.2, U1.M10 (TDO)
/JTAG_TMS: JTAG1.4, R43.2, U1.T11 (TMS)
/LED1: J3.9, U2.3 (LED1/REGOFF)
/LED2: J3.11, U2.2 (LED2/nINTSEL)
/LED_B: R49.2, U1.E1 (PL20D/-/LDQ17)
/LED_G: R48.2, U1.C1 (PL14A/+/HS/LDQ17)
/LED_R: R47.2, U1.G1 (PL29A/+/GR_PCLK7_1/HS/LDQS29)
/PMOD_A1: PMOD1.1 (IOA0), U1.K3 (PL29D/-/LDQ29)
/PMOD_A2: PMOD1.2 (IOA1), U1.J2 (PL32B/-/PCLKC7_1/HS/LDQ29)
/PMOD_A3: PMOD1.3 (IOA2), U1.J3 (PL29C/+/GR_PCLK7_0/LDQ29)
/PMOD_A4: PMOD1.4 (IOA3), U1.F1 (PL23A/+/HS/LDQ29)
/PMOD_A7: PMOD1.7 (IOB0), U1.K2 (PL32D/-/PCLKC7_0/LDQ29)
/PMOD_A8: PMOD1.8 (IOB1), U1.K1 (PL32C/+/PCLKT7_0/LDQ29)
/PMOD_A9: PMOD1.9 (IOB2), U1.J1 (PL32A/+/PCLKT7_1/HS/LDQ29)
/PMOD_A10: PMOD1.10 (IOB3), U1.G2 (PL23B/-/HS/LDQ29)
/PMOD_B1: PMOD2.1 (IOA0), U1.N5 (PL65D/-/LDQ65)
/PMOD_B2: PMOD2.2 (IOA1), U1.M5 (PL65C/+/LDQ65)
/PMOD_B3: PMOD2.3 (IOA2), U1.T4 (PL65B/-/HS/LDQSN65)
/PMOD_B4: PMOD2.4 (IOA3), U1.P4 (PL62A/+/HS/LDQ65)
/PMOD_B7: PMOD2.7 (IOB0), U1.N6 (PL68B/-/HS/LDQ65)
/PMOD_B8: PMOD2.8 (IOB1), U1.M6 (PL68A/+/HS/LDQ65)
/PMOD_B9: PMOD2.9 (IOB2), U1.R5 (PL65A/+/HS/LDQS65)
/PMOD_B10: PMOD2.10 (IOB3), U1.P5 (PL68D/-/LLC_GPLL0C_IN/LDQ65)
/PROGRAMN: R3.2, R9.2, U1.R9 (PROGRAMN)
/PWR1V1: C2.2, C4.2, C9.2, C10.2, C11.2, C12.2, C51.1, C52.1, C55.1, C56.1, L2.2, R52.1, TP4.1, U1.G6 (VCC[6]), U1.G7 (VCC[6]), U1.G9 (VCC[6]), U1.L8 (VCC[6]), U1.L9 (VCC[6]), U1.L10 (VCC[6])
/PWR1V1EN: R51.2, U6.1 (EN), U7.5 (PG)
/PWR1V35: C13.2, C15.2, C45.1, C46.1, FB3.2, FB4.2, L1.2, R39.1, R45.1, TP3.1, U1.H11 (VCCIO2[2]), U1.J11 (VCCIO2[2]), U1.K11 (VCCIO3[2]), U1.L11 (VCCIO3[2])
/PWR2V5: C3.2, C54.1, U1.G11 (VCCAUX[2]), U1.L7 (VCCAUX[2]), U8.5 (OUT)
/PWR3V3: C1.2, C5.2, C6.2, C7.2, C8.2, C16.1, C17.1, C36.1, C40.1, C41.1, C47.1, C50.1, C53.1, C57.1, C58.1, D1.1 (A), FB2.2, J5.4 (VDD), JTAG1.5, L3.2, MMOD1.6 (VCC), PMOD1.6 (VCC), PMOD1.12 (VCC), PMOD2.6 (VCC), PMOD2.12 (VCC), R1.1, R2.1, R3.1, R4.1, R11.1, R12.1, R31.1, R32.1, R33.1, R34.1, R35.1, R36.1, R37.1, R38.1, R42.1, R43.1, R50.2, R54.1, TP5.1, U1.F6 (VCCIO0[2]), U1.F7 (VCCIO0[2]), U1.F10 (VCCIO1[2]), U1.F11 (VCCIO1[2]), U1.H6 (VCCIO7[2]), U1.H7 (VCCIO7[2]), U1.J6 (VCCIO6[2]), U1.J7 (VCCIO6[2]), U1.L6 (VCCIO8), U2.9 (VDDIO), U4.1 (INH), U4.4 (VCC), U8.1 (IN), U8.3 (EN), Y1.1 (INH), Y1.4 (VCC)
/PWR3V3A: C19.1, C21.1, C33.1, FB2.1, J3.4, J3.5, R15.1, R16.1, R17.1, R18.1, R30.1, U2.1 (VDD2A), U2.19 (VDD1A)
/PWR5V0: C14.1, C44.1, C48.1, C49.1, FB1.1, FB5.1, R51.1, TP1.1, U5.1 (EN), U5.4 (VIN), U6.4 (VIN), U7.1 (EN), U7.4 (VIN)
/PWR5V0UF: FB1.2, J1.A4 (VBUS), J1.A9 (VBUS), J1.B4 (VBUS), J1.B9 (VBUS), J4.1
/RESET: R9.1, U1.M8 (PB15B/-/DOUT/CSON)
/SD_CD: R35.2, R41.1, U1.A5 (PT18A/+)
/SD_DAT1: J5.8 (DAT1), R36.2, U1.B5 (PT15B/-)
/SD_DAT2: J5.1 (DAT2), R37.2, U1.A2 (PT4A/+/ULC_GPLL1T_IN)
/SD_MISO: J5.7 (DAT0), R31.2, U1.A4 (PT6B/-)
/SD_MOSI: J5.3 (CMD), R33.2, U1.A3 (PT6A/+)
/SD_SCK: J5.5 (CLK), R32.2, U1.B4 (PT11B/-)
/SD_SS: J5.2 (DAT3/CD), R34.2, U1.B3 (PT4B/-/ULC_GPLL1C_IN)
/UART_RX: J6.2, U1.B2 (PL11B/-/ULC_GPLL0C_IN/HS/LDQ17)
/UART_TX: J6.1, U1.B1 (PL11A/+/ULC_GPLL0T_IN/HS/LDQ17)
/USB0_CONN_DN: J1.A7 (DN1), J1.B7 (DN2), R8.1
/USB0_CONN_DP: J1.A6 (DP1), J1.B6 (DP2), R6.2, R7.1
/USB0_DN: R8.2, U1.R6 (PB4B/-/D6/IO6)
/USB0_DP: R7.2, U1.T6 (PB4A/+/D7/IO7)
/USB0_DP_PU: R6.1, U1.R7 (PB6A/+/D5/MISO2/IO5)
/USB1_CONN_DN: J2.2 (D1-), R24.1, R28.1
/USB1_CONN_DP: J2.3 (D1+), R23.1, R27.1
/USB1_DN: R24.2, U1.T3 (PL62D/-/LDQ65)
/USB1_DP: R23.2, U1.R4 (PL62C/+/LDQ65)
/USB2_CONN_DN: J2.6 (D2-), R22.1, R26.1
/USB2_CONN_DP: J2.7 (D2+), R19.1, R25.1
/USB2_DN: R26.2, U1.R1 (PL44B/-/VREF1_6/HS/LDQ41)
/USB2_DP: R25.2, U1.P1 (PL44A/+/HS/LDQ41)
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

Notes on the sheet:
K O P F L O S
nINTSEL has internal pull-up, which selects REF_CLK In mode
PWR3V3 COMES UP FIRST FOR MASTER SPI MODE, ECP5 DATASHEET SECTION 3.5
0.6 * (1 + (210/47)) = 3.28
REGOFF has internal pull-down, which enables internal 1.2V regulator
MMOD has a 10K pull-up on CSPI_SS
0.6 * (1 + (100/120)) = 1.099
0.6 * (1 + (150/120)) = 1.35

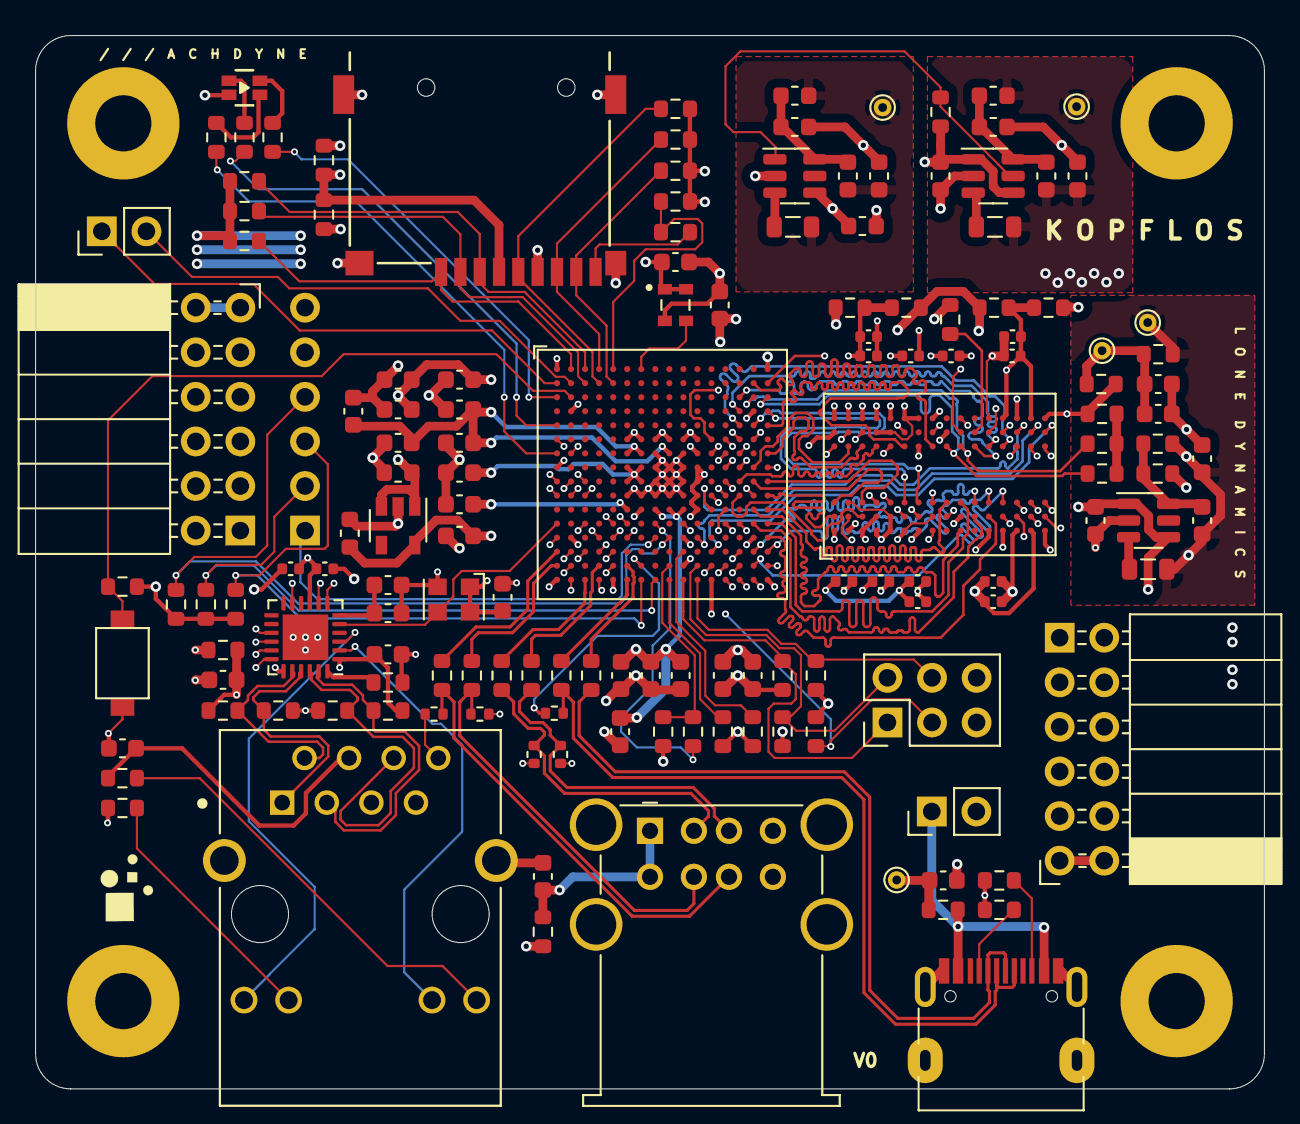
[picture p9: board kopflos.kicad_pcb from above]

Board: 6 copper layers, 70.0 x 60.0 mm, 151 parts (1 on the bottom side), 150 nets.

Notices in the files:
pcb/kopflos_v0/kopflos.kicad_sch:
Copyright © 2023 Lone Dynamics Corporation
